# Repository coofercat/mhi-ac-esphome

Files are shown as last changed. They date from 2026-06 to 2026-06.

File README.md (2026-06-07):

# Mitsubishi Heavy Industries (MHI) Air Conditioner to ESPHome

## Mitsubishi, or Mitsubishi?

There are two companies with competing air conitioner products. There's **Mitsubishi Electric Corporation** and **Mitsubishi Heavy Industries**. This project refers to the **Mitsubishi Heavy Industries (MHI)** line only. If you have a Mitsubishi Electric Corporation air conditioner, this project is not compatible (although extremely similar).

## What is this project?

This project integrated an MHI air conditioner with ESPHome and Home Assistant. It's not an original project, it builds on these excellent works:

- Probably the start of everything: https://github.com/absalom-muc/MHI-AC-Ctrl
- An excellent project by Wouter in the original [Dutch](https://www.twoenter.nl/blog/smarthome/mitsubishi-airco-voorzien-van-wifi-besturing/) or [English](https://www.twoenter.nl/blog/en/smarthome-en/mitsubishi-air-conditioner-equipped-with-wi%e2%80%91fi-control-using-mhi%e2%80%91ac%e2%80%91ctrl/)
- Another excellent project from which this project borrows software: https://github.com/ginkage/MHI-AC-Ctrl-ESPHome

The difference between this project and those above is that this one doesn't need a circuit board. It's assembled using some (hopefully) easy to source components, some wires and some sort of a plastic box (which can be 3D printed if you want).

## Ingredients

This project needs some components which are hopefully easy to source. They are:

- An ESP32. I used an ESP32 WROOM dev kit, it's the 38 pin type of ESP32. Something like these: https://www.amazon.co.uk/AZDelivery-unsoldered-Development-successor-compatible/dp/B0BFDL7W6N
- A 4 channel level shifter, something like this: https://www.amazon.co.uk/dp/B082F6BSB5
- A 5V buck converter, something like this: https://www.amazon.co.uk/dp/B0DY11F6N5
- A JST 2.54mm XH 5 pin connector (I bought these: https://www.amazon.co.uk/dp/B0CRZF4GCV)
- A 4K7 resistor (although maybe 3K9 or 3K3 would be better?)
- some wires, soldering iron, patience, etc.

Pretty much any ESP32 would probably work fine. As far as I know they all have SPI pins available, so they'll be fine for this. You absolutely need a level shifter because the aircon unit has 5V signals which will damage an ESP if they aren't shifted down to 3.3V first.
The aircon unit supplies 12V, so I used a buck converter to make 5V and to keep the heat down. I also picked a fixed 5V variety so that there was much less chance of accidentally getting anything other than 5V out of it.

With regards the resistor, this is required to pull the MISO pin low during power up. If it's not held low, the level shifter seems to pull it high enough that it stop the ESP32 from booting properly. I used 4K7s for mine, but in one case I had to substitute a 3K9 to make it work. As such, a slightly lower value may be preferable for all new implementations.

When I bought the connector, it came with pre-crimped wires attached, and also came with sockets as well as the needed plug. Actually, this turned out really helpful because I was able to make an extension lead which I was able to put into the aircon unit and leave it dangling outside when the cover was back on. That made debug and development much easier!

## How to make it

Before you start, I recommend getting your ESP32 flashed with the ESPHome software. Initially this requires plugging it in with a cable, so it's easiest to get that done before you do any soldering or fitting it into a box. Once it's done, you can update it wirelessly.

For software, see [SOFTWARE.md](SOFTWARE.md).

## Electronics

I made a Fritzing diagram of the circuit required. In the diagram, I couldn't find a component that looked exactly like my buck converters, and nor could I find the particular connector, but I'm sure it's clear enough to figure out what to do.

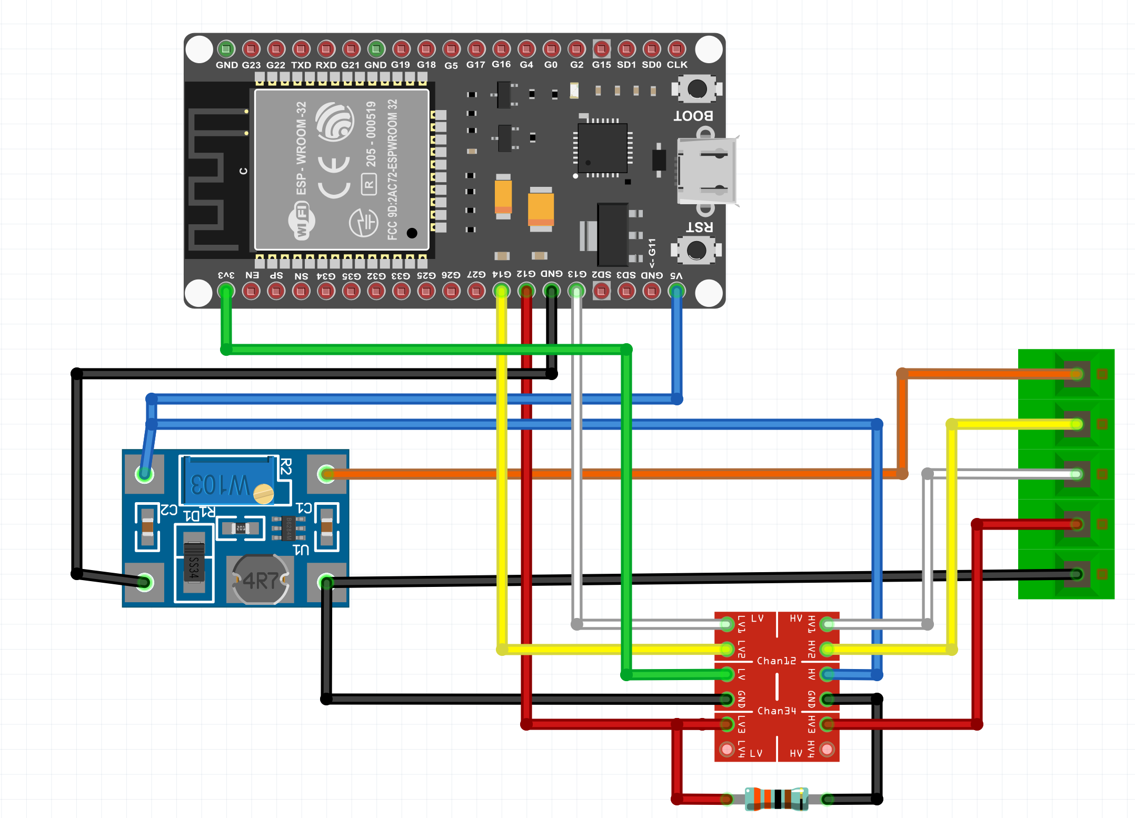
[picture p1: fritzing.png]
Fritzing diagram


I found I could use the spare ground on the level shifter (on the HV side) as a place to bridge in the resistor to pull down the MISO line. I ended up with this:

Final Build

I made a small 3D printed box with a sliding lid (Sketchup and STL files are in the `3dprinter` directory). The box is small enough that it can be placed in the space behind the metal cover that goes over the side circuit board. The box provides convenient electrical and physical protection, whilst also mounting and spacing the components quite easily. I bent the ESP's pins we're using sideways and trimmed off the other pins (my ESPs came fully soldered). This helps keep the box thin so it fits in the AC unit easily. I stuck the boards down using small sticky pads, although screws are also possible.

## Fitting the project to the aircon unit

See [FITTING.md](FITTING.md)

## A note about ESP32s, the MISO line, strapping pins and annoyances!

ESP32s have something called "strapping pins". These are used during initial boot to figure out what to do. For whatever reason, many (all?) ESP32s use whatever pin is connected to the internal SPI interface's MISO line as a strapping pin. This means you have to pull that pin low (or leave it unconnected) to get the ESP to boot.

I found that even just connecting that pin to the level shifter was enough to make it float high enough that the ESP wouldn't boot. It also turns out that the MISO line on the MHI aircon is pulled high before you even connect to it. The only solution was to pull it low as part of this project. It's a pain because it means you need to fit a single resistor. It also has the potential to degrade the signal from the MHI to the ESP32, making the prospect of 'frame errors' or dropped commands more likely.

I played with a number of different values of resistor. I found that 4K7 was the highest I could use to make it work, but in one of the devices I made, it didn't work even with that. I used a 3K9 to resolve that problem, and it seems to work okay, so maybe 3K9 or even 3K3 is a better choice. I don't know for sure, but I suspect lower values will degrade the signal, so I'd advise keeping it as high as possible. Either way, it seems that pulling it low on the ESP side of the level shifters is beneficial.

Another thing to note is that an ESP that isn't booting because of a strapping problem seems to blink the onboard LED rapidly. Similarly, a properly working, but not-yet-connected ESP also flashes its LED quite rapidly. Whilst the description is the same, if you look carefully there is a difference, but its easy to miss if you don't look carefully enough.

Whilst diagnosing this problem, I also found some people recommending putting a 10uF capacitor between the EN (Reset) line and ground. This allows buck converters time to fully reach their output voltage before the ESP tries to boot. I didn't find this to be necessary, but it's possible different ESP models, or even different board types, different buck converters (etc) may have different characteristics. if so, you may need to add one of these too.

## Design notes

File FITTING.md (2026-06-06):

# Fitting the project to the Aircon Unit

Make sure to turn the power off before doing this. In my case that means going down a couple of flights of stairs. Don't be lazy, it's dangerous inside the unit, so play it safe!

First of all, take the front door off the unit to end up with something like this:

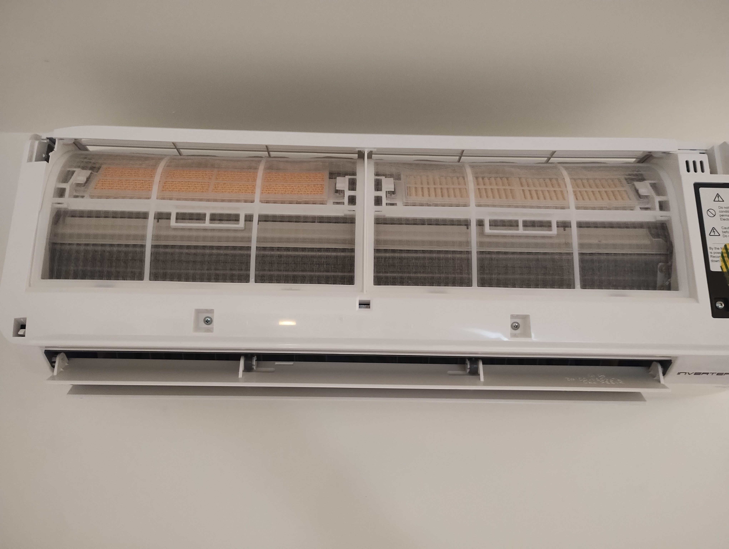
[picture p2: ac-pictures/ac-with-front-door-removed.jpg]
front door removed


Remove the filters (mine were pretty clean, but now's a great time to clean up a bit!). Next, locate and remove the two screws in the front of the unit. Also find the two hidden screws covered with a sort of clip:

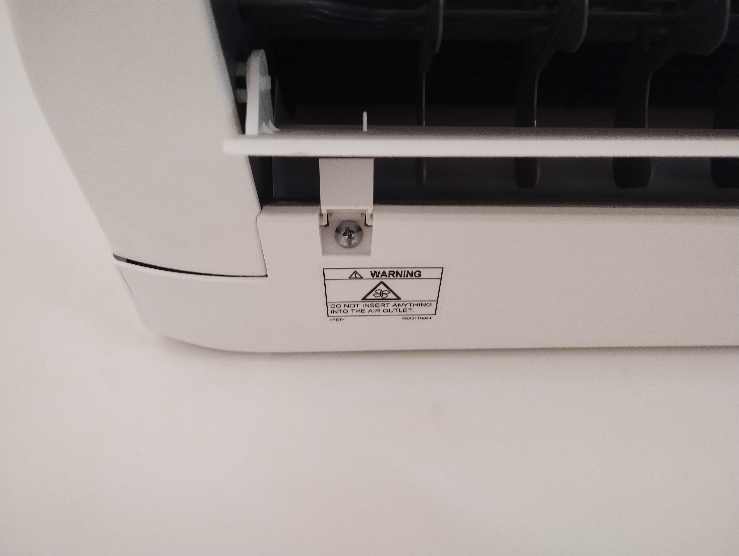
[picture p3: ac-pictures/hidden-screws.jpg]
hidden screws


Getting the cover off the aircon unit is probably the worst part of this work. I'm sure there's a nice trick to it, but I couldn't figure out how to do it without making some pretty scary sounding cracking noises and bending plastic more than I'd imagine should be necessary. In short, there
are three "one way" clips at the back on top of the unit. These clips don't come out easily, and even when you've got the cover at a difficult angle, they still don't want to come out "nicely". The best I could do was a bit of brute force and ignorance, and then the main cover came off.

Once it's off, you can locate the cover over the circuit board on the right hand side:

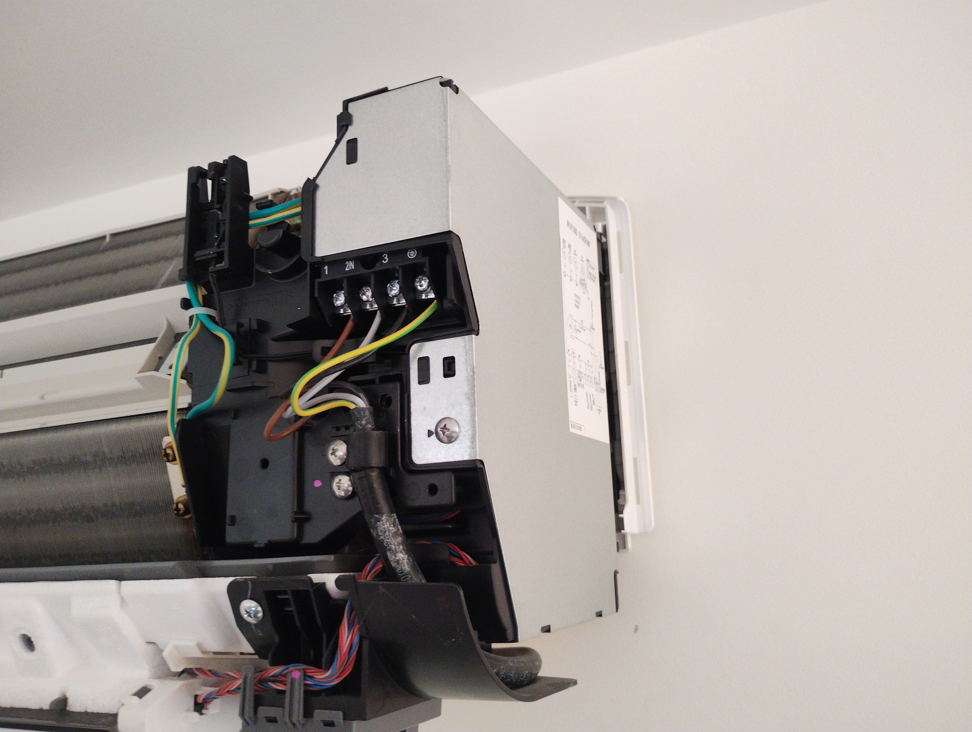
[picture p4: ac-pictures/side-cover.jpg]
side cover


Remove that cover to reveal the circuit board:

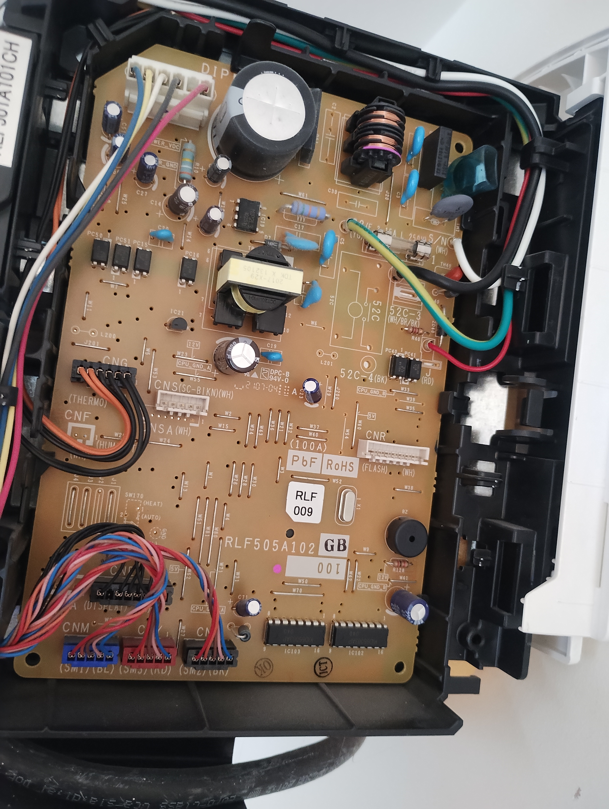
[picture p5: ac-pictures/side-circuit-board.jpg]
side circuit board


Locate the connector marked **CNS(SC-BIKIN)(WH)** and **CNSA(WH)**. If you have a connector marked CN105, then you have a Mitsubishi Electric aircon, and need a slightly different project!

On CNSA, the pinout from left to right on my photo is:

1. +12V (orange in my circuit)
2. SCL (yellow in my circuit)
3. MOSI (white in my circuit)
4. MISO (red in my circuit)
5. GND (black in my circuit)

Accidentally connecting +12V to any of the other 4 pins is likely to end up damaging your aircon unit. Be careful!

I was able to simply plug my project into the connector, and the place the box towards the back at the bottom of the circuit board, and then cover it with the metal cover before re-assembling the unit.

However you fit it, I recommend you check that it works before putting the plastic covers back onto the AC unit. They're hard to get off, so you don't want to have to do it more often than necessary.

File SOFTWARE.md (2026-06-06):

# Software

Before you go very far, you'll need to flash the ESPHome software onto your ESP32. This will involve connecting it up with a cable to wherever you run ESPHome (in my case, that's my Home Assistant server). How you do this depends on your situation, I'll assume you know how to do it (if not, there are some good guides on the ESPHome website and around the web).

I used the code below to make my project work. It leverages this project: https://github.com/ginkage/MHI-AC-Ctrl-ESPHome. There's lots of great information there, including lots of debugging and troubleshooting information. The main thing to check is the "frame size". If you get a lot of `mhi_ac_ctrl_core.loop error: -2` in the log, then change the frame size. It's all marked up in the code below.

It's perfectly okay to run the ESP without connecting it to an actual aircon unit. It's well worth trying it while it's still on the desk, but it'll emit a lot of `mhi_ac_ctrl_core.loop error: -4` errors. Each of these flashes the on-board LED too, so it's actually quite easy to see if it's running just by looking at it.

```
esphome:
  name: mitsubishi-aircon-1
  friendly_name: mitsubishi-aircon-1
  min_version: 2024.6.0
  platformio_options:
    # Run CPU at 160Mhz to fix mhi_ac_ctrl_core.loop error: -2
    board_build.f_cpu: 160000000L

esp32:
  board: esp32dev
  framework:
    type: arduino

# Enable logging
logger:

# Enable Home Assistant API
api:
  encryption:
    key: !secret ha_api_encryption
  services:
    - service: set_external_room_temperature
      variables:
        temperature_value: float # temperature to set in Celsius
      then:
        - climate.mhi.set_external_room_temperature:
            temperature: !lambda "return temperature_value;"

ota:
  - platform: esphome
    password: !secret esphome_ota_password

wifi:
  ssid: !secret wifi_ssid
  password: !secret wifi_password
  fast_connect: True

  # Enable fallback hotspot (captive portal) in case wifi connection fails
  ap:
    ssid: "Mitsubishi-Aircon-1"
    password: "changeMe"

captive_portal:

external_components:
  - source: github://ginkage/MHI-AC-Ctrl-ESPHome@master
    components: [MhiAcCtrl]

# Version 4.2

MhiAcCtrl:
  # Only 20 (legacy) or 33 (includes 3D auto and vertical vanes) possible.
  # If you encounter mhi_ac_ctrl_core.loop error: -2 errors, change the frame_size to 20
  frame_size: 33
  sck_pin: 14
  mosi_pin: 13
  miso_pin: 12
  initial_vertical_vanes_position: 5
  initial_horizontal_vanes_position: 8
  # Update the following to change the default room temp timeout
  room_temp_timeout: 60

button:
  - platform: restart
    name: Restart
    entity_category: diagnostic

climate:
  - platform: MhiAcCtrl
    name: "MHI Air Conditioner"
    temperature_offset: true
    visual_min_temperature: 17.0
    visual:
      temperature_step:
        target_temperature: 0.5
        current_temperature: 0.1

time:
  - platform: homeassistant
    id: homeassistant_time

binary_sensor:
  - platform: MhiAcCtrl
    defrost:
      name: "Defrost"
    vanes_3d_auto_enabled:
      name: "3D Auto"

sensor:
  - platform: uptime
    name: Uptime
  - platform: wifi_signal
    name: WiFi Signal
    update_interval: 60s
  - platform: MhiAcCtrl
    outdoor_temperature:
      name: "Outdoor temperature"
    return_air_temperature:
      name: "Return air temperature"
    outdoor_unit_fan_speed:
      name: "Outdoor unit fan speed"
    indoor_unit_fan_speed:
      name: "Indoor unit fan speed"
    compressor_frequency:
      name: "Compressor frequency"
    indoor_unit_total_run_time:
      name: "Indoor unit total run time"
    compressor_total_run_time:
      name: "Compressor total run time"
    current_power:
      name: "Current power"
    energy_used:
      name: "Energy used"
    indoor_unit_thi_r1:
      name: "Indoor (U-bend) HE temp 1"
    indoor_unit_thi_r2:
      name: "Indoor (capillary) HE temp 2"
    indoor_unit_thi_r3:
      name: "Indoor (suction header) HE temp 3"
    outdoor_unit_tho_r1:
      name: "Outdoor HE temp"
    outdoor_unit_expansion_valve:
      name: "Outdoor unit exp. valve"
    outdoor_unit_discharge_pipe:
      name: "Outdoor unit discharge pipe"
    outdoor_unit_discharge_pipe_super_heat:
      name: "Outdoor unit discharge pipe super heat"
    protection_state_number:
      name: "Compressor protection code"
    error_code:
      name: "Error code"
    vanes_pos:
      name: "Vanes"
    vanesLR_pos:
      name: "Vanes Left-Right"

text_sensor:
  - platform: version
    name: ESPHome Version
  - platform: wifi_info
    ip_address:
      name: IP
    ssid:
      name: SSID
    bssid:
      name: BSSID
  - platform: MhiAcCtrl
    protection_state:
      name: "Compressor protection status"

select:
  - platform: MhiAcCtrl
    vertical_vanes:
      name: Fan Control Up Down
    horizontal_vanes:
      name: Fan Control Left Right
    fan_speed:
      name: "Fan Speed"

switch:
  - platform: MhiAcCtrl
    vanes_3d_auto:
      name: "3D Auto"
```

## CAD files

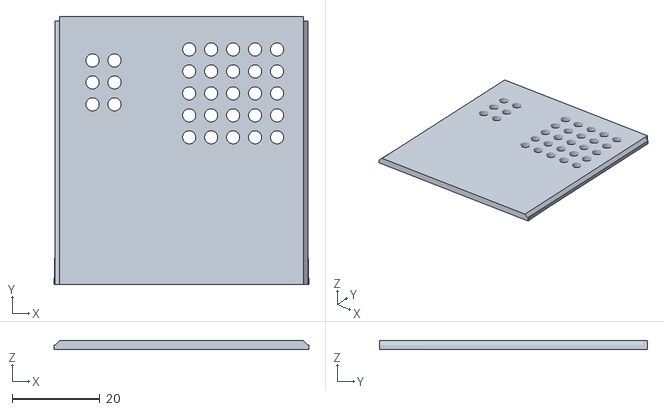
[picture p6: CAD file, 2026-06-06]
3dprinter/esp-box-lid.stl
58.0 x 61.0 x 2.00

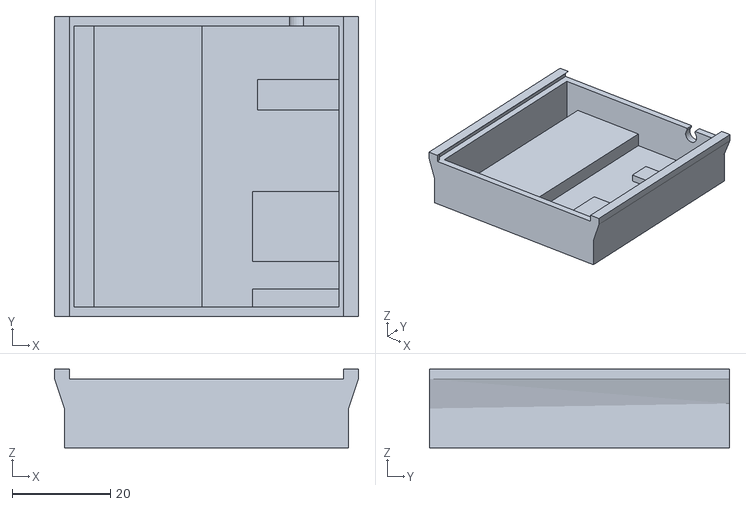
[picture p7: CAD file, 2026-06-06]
3dprinter/esp-box-bottom.stl
61.8 x 61.0 x 16.0

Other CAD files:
3dprinter/esp-box-bottom.skp
3dprinter/esp-box-lid.skp
